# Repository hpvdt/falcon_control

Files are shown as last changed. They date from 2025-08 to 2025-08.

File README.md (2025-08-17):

>[!WARNING]
>The functionality of this board has been split between the new wing modules and flight sticks, so this hardware is redundant and will no longer be worked on.

# Control Board

This board is primarily meant to collect the inputs from the flight sticks over I2C and then operate control surface servos. In addition to this it also has the functionlity to read potentiometers on the control surfaces to verify the control surfaces are moving into the right position and even alerting the pilots if they fail to using a buzzer for attention and LEDs to specify the problematic surfaces.

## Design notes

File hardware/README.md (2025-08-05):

# Hardware

KiCad projects for the control boards.

## Revision 3

Most recent board. Current candidate for installation into Falcon.

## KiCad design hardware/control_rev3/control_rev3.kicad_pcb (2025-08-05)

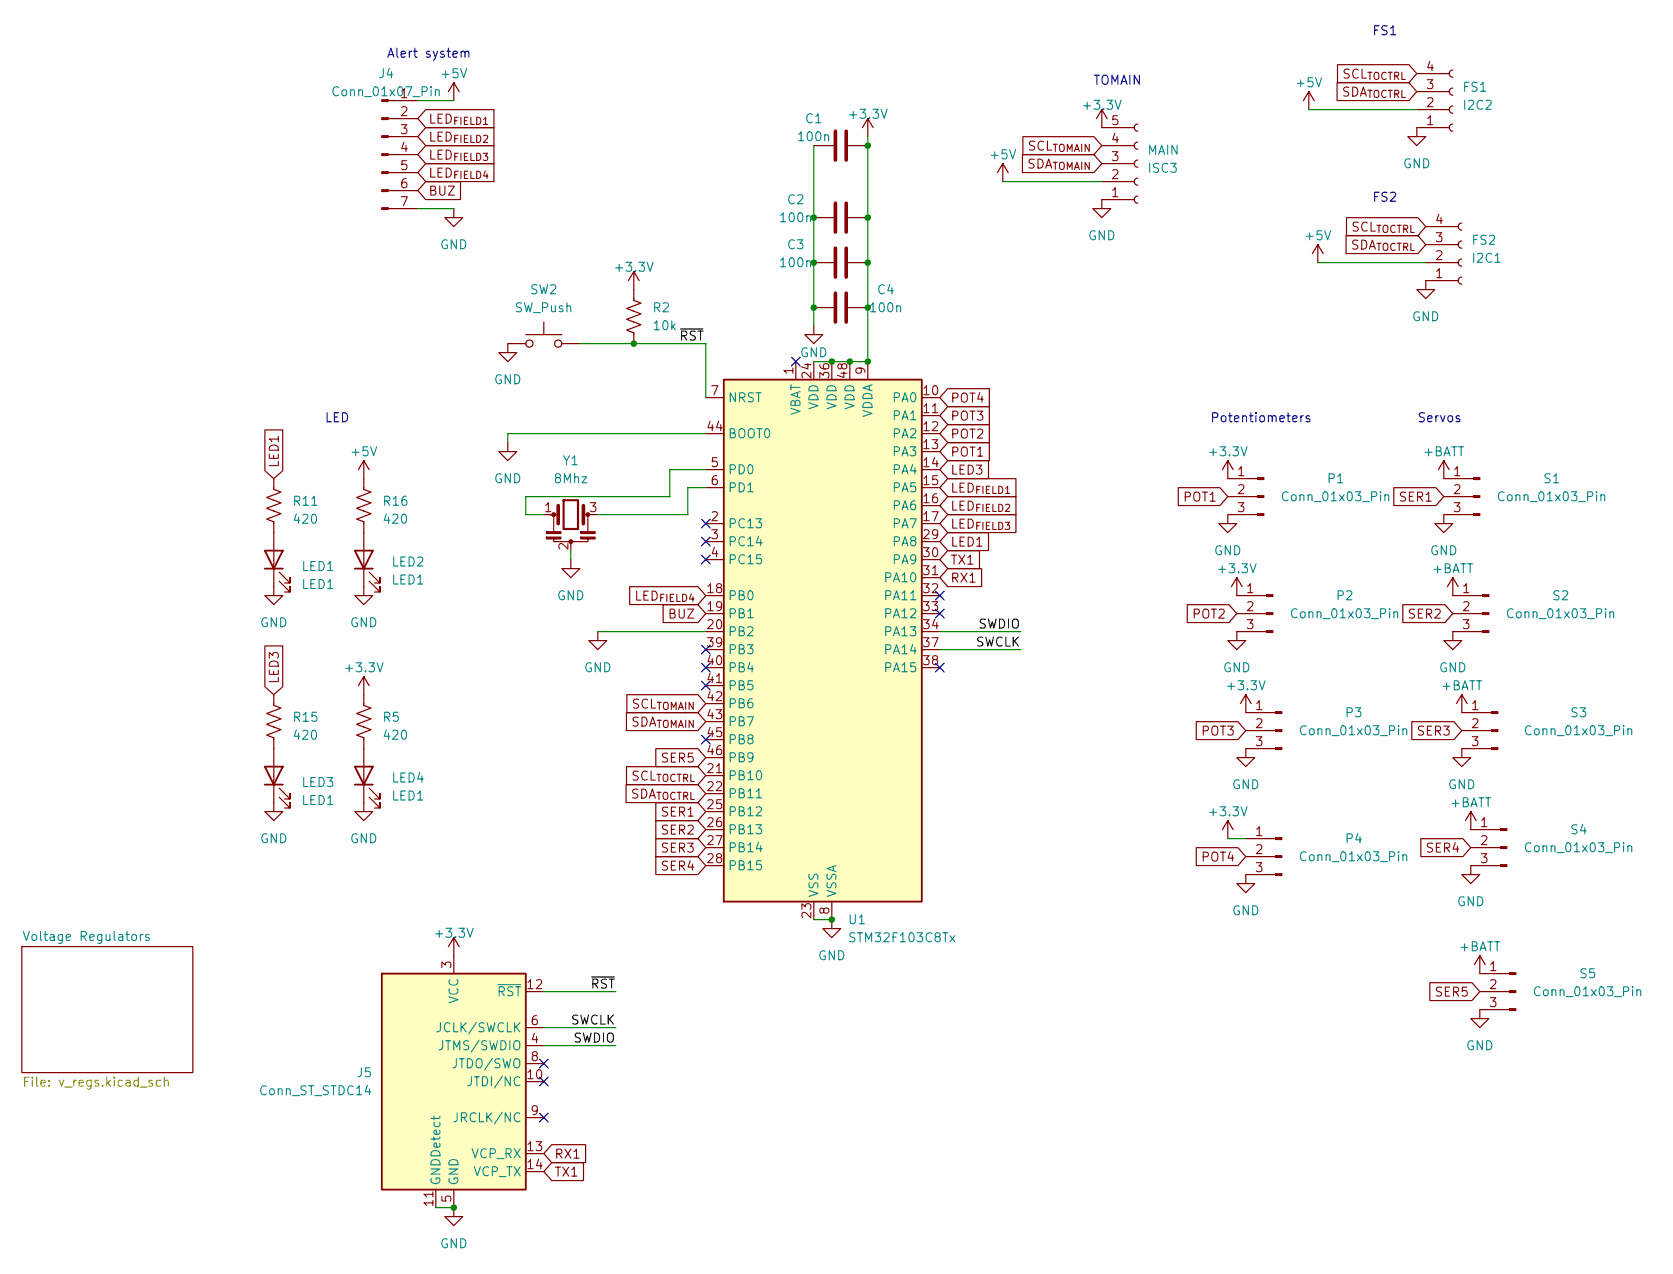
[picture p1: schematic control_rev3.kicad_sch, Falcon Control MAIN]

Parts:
C1, C2, C3, C4: 100n; C_0603_1608Metric
I2C1: FS2; JST_XH_B4B-XH-A_1x04_P2.50mm_Vertical
I2C2: FS1; JST_XH_B4B-XH-A_1x04_P2.50mm_Vertical
ISC3: MAIN; JST_XH_B5B-XH-A_1x05_P2.50mm_Vertical
J4: Conn_01x07_Pin; JST_XH_B7B-XH-A_1x07_P2.50mm_Vertical
J5: Conn_ST_STDC14; PinHeader_2x07_P1.27mm_Vertical_SMD
LED1, LED2, LED3, LED4: LED1; LED_0805_2012Metric_Pad1.15x1.40mm_HandSolder
P1, P2, P3, P4: Conn_01x03_Pin; JST_EH_B3B-EH-A_1x03_P2.50mm_Vertical
R2: 10k; R_0603_1608Metric
R5, R11, R15, R16: 420; R_0603_1608Metric
S1, S2, S3, S4, S5: Conn_01x03_Pin; JST_EH_B3B-EH-A_1x03_P2.50mm_Vertical
SW2: SW_Push; SW_SPST_B3U-1000P-B
U1: STM32F103C8Tx; LQFP-48_7x7mm_P0.5mm
Y1: 8Mhz; Resonator_SMD_Murata_CSTxExxV-3Pin_3.0x1.1mm

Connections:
+3.3V: C1.2, C2.2, C3.2, C4.1, ISC3.5, J5.3 (VCC), P1.1, P2.1, P3.1, P4.1, R2.1, R5.2, U1.9 (VDDA), U1.24 (VDD), U1.36 (VDD), U1.48 (VDD); also elsewhere on the board
+5V: I2C1.2, I2C2.2, ISC3.2, J4.1, R16.2; also elsewhere on the board
+BATT: S1.1, S2.1, S3.1, S4.1, S5.1; also elsewhere on the board
/SWCLK: J5.6 (JCLK/SWCLK), U1.37 (PA14)
/SWDIO: J5.4 (JTMS/SWDIO), U1.34 (PA13)
/~RST: J5.12 (~RST), R2.2, SW2.2, U1.7 (NRST)
BUZ: J4.6, U1.19 (PB1)
GND: C1.1, C2.1, C3.1, C4.2, I2C1.1, I2C2.1, ISC3.1, J4.7, J5.5 (GND), J5.7 (GND), J5.11 (GNDDetect), LED1.1 (K), LED2.1 (K), LED3.1 (K), LED4.1 (K), P1.3, P2.3, P3.3, P4.3, S1.3, S2.3, S3.3, S4.3, S5.3, SW2.1, U1.8 (VSSA), U1.20 (PB2), U1.23 (VSS), U1.35 (VSS), U1.44 (BOOT0), U1.47 (VSS), Y1.2; also elsewhere on the board
LED1: R11.2, U1.29 (PA8)
LED3: R15.2, U1.14 (PA4)
LED_{FIELD1}: J4.2, U1.15 (PA5)
LED_{FIELD2}: J4.3, U1.16 (PA6)
LED_{FIELD3}: J4.4, U1.17 (PA7)
LED_{FIELD4}: J4.5, U1.18 (PB0)
unnamed: LED1.2 (A), R11.1
unnamed: LED2.2 (A), R16.1
unnamed: LED3.2 (A), R15.1
unnamed: LED4.2 (A), R5.1
unnamed: U1.5 (PD0), Y1.1
unnamed: U1.6 (PD1), Y1.3
POT1: P1.2, U1.13 (PA3)
POT2: P2.2, U1.12 (PA2)
POT3: P3.2, U1.11 (PA1)
POT4: P4.2, U1.10 (PA0)
RX1: J5.13 (VCP_RX), U1.31 (PA10)
SCL_{TOCTRL}: I2C1.4, I2C2.4, U1.21 (PB10)
SCL_{TOMAIN}: ISC3.4, U1.42 (PB6)
SDA_{TOCTRL}: I2C1.3, I2C2.3, U1.22 (PB11)
SDA_{TOMAIN}: ISC3.3, U1.43 (PB7)
SER1: S1.2, U1.25 (PB12)
SER2: S2.2, U1.26 (PB13)
SER3: S3.2, U1.27 (PB14)
SER4: S4.2, U1.28 (PB15)
SER5: S5.2, U1.46 (PB9)
TX1: J5.14 (VCP_TX), U1.30 (PA9)

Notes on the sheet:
FS1
Servos
Alert system
FS2
TOMAIN
Potentiometers
LED

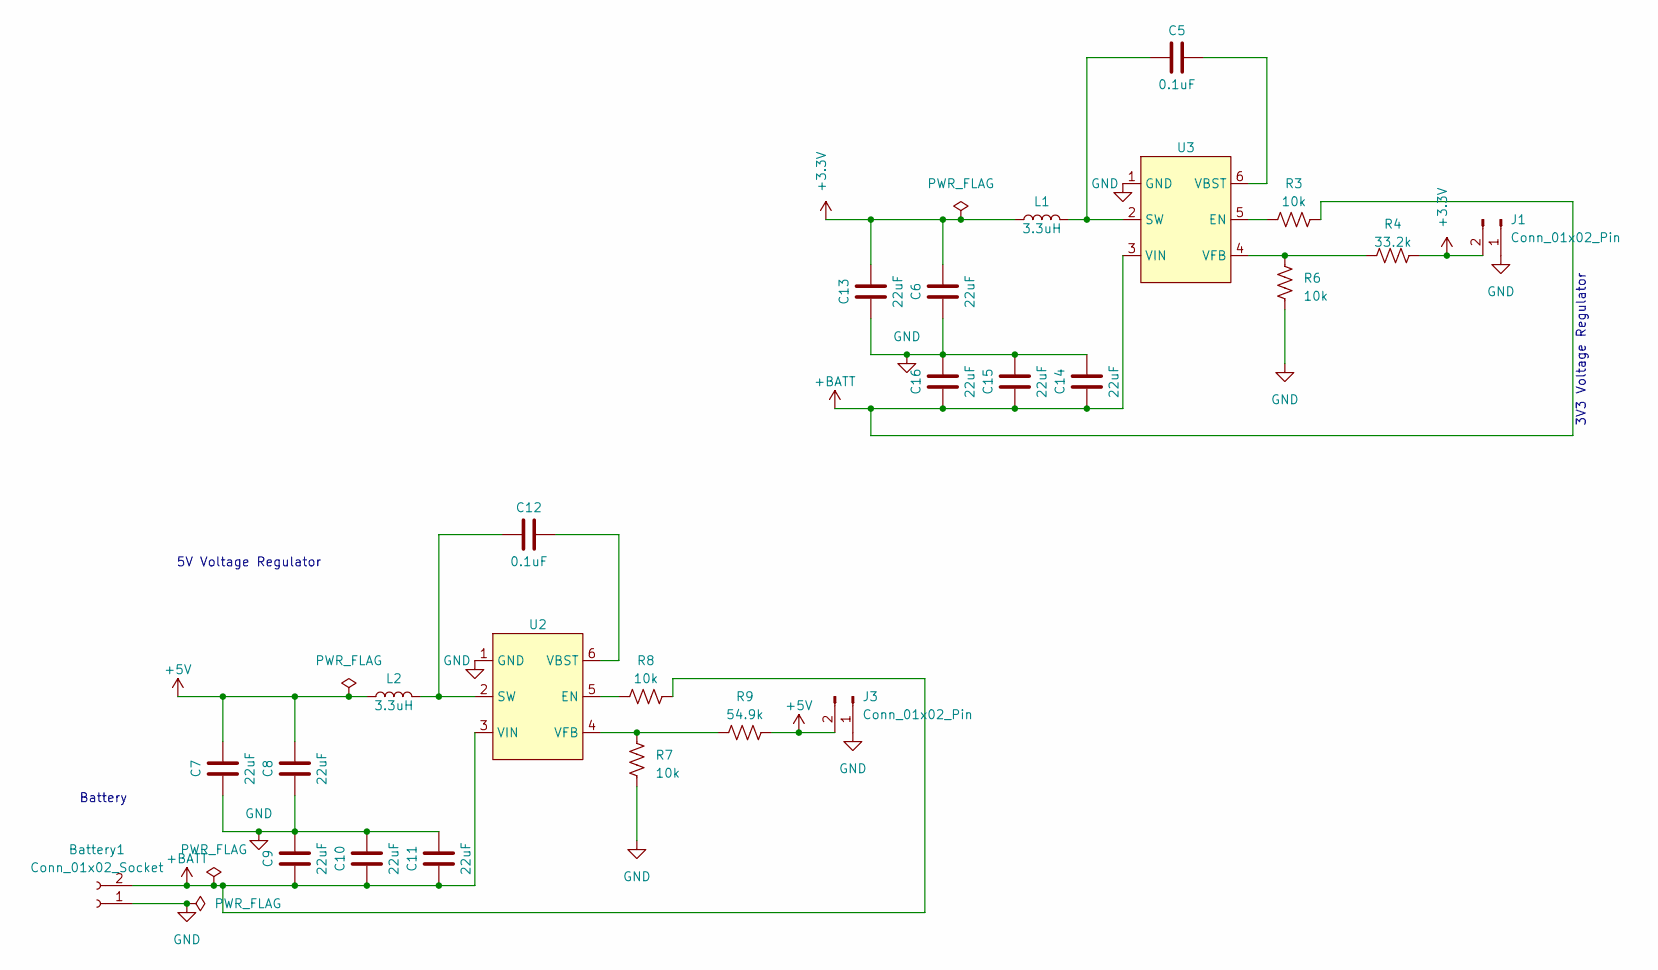
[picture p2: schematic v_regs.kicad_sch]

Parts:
Battery1: Conn_01x02_Socket; AMASS_XT60-M_1x02_P7.20mm_Vertical
C5, C12: 0.1uF; C_0805_2012Metric
C6, C7, C8, C9, C10, C11, C13, C14, C15, C16: 22uF; C_0805_2012Metric
J1, J3: Conn_01x02_Pin; JST_XH_B2B-XH-A_1x02_P2.50mm_Vertical
L1, L2: 3.3uH; L_Taiyo-Yuden_NR-60xx
R3, R6, R7, R8: 10k; R_0603_1608Metric
R4: 33.2k; R_0603_1608Metric
R9: 54.9k; R_0603_1608Metric
U2, U3: TSOT-23-6

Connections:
+3.3V: C6.2, C13.2, J1.2, L1.1, R4.1; also elsewhere on the board
+5V: C7.2, C8.2, J3.2, L2.1, R9.1; also elsewhere on the board
+BATT: Battery1.2, C9.1, C10.1, C11.1, C14.1, C15.1, C16.1, R3.2, R8.2, U2.3 (VIN), U3.3 (VIN); also elsewhere on the board
GND: Battery1.1, C6.1, C7.1, C8.1, C9.2, C10.2, C11.2, C13.1, C14.2, C15.2, C16.2, J1.1, J3.1, R6.1, R7.1, U2.1 (GND), U3.1 (GND); also elsewhere on the board
unnamed: R8.1, U2.5 (EN)
unnamed: C12.1, L2.2, U2.2 (SW)
unnamed: C12.2, U2.6 (VBST)
unnamed: R7.2, R9.2, U2.4 (VFB)
unnamed: R3.1, U3.5 (EN)
unnamed: C5.1, L1.2, U3.2 (SW)
unnamed: C5.2, U3.6 (VBST)
unnamed: R4.2, R6.2, U3.4 (VFB)

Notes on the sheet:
5V Voltage Regulator
3V3 Voltage Regulator
Battery

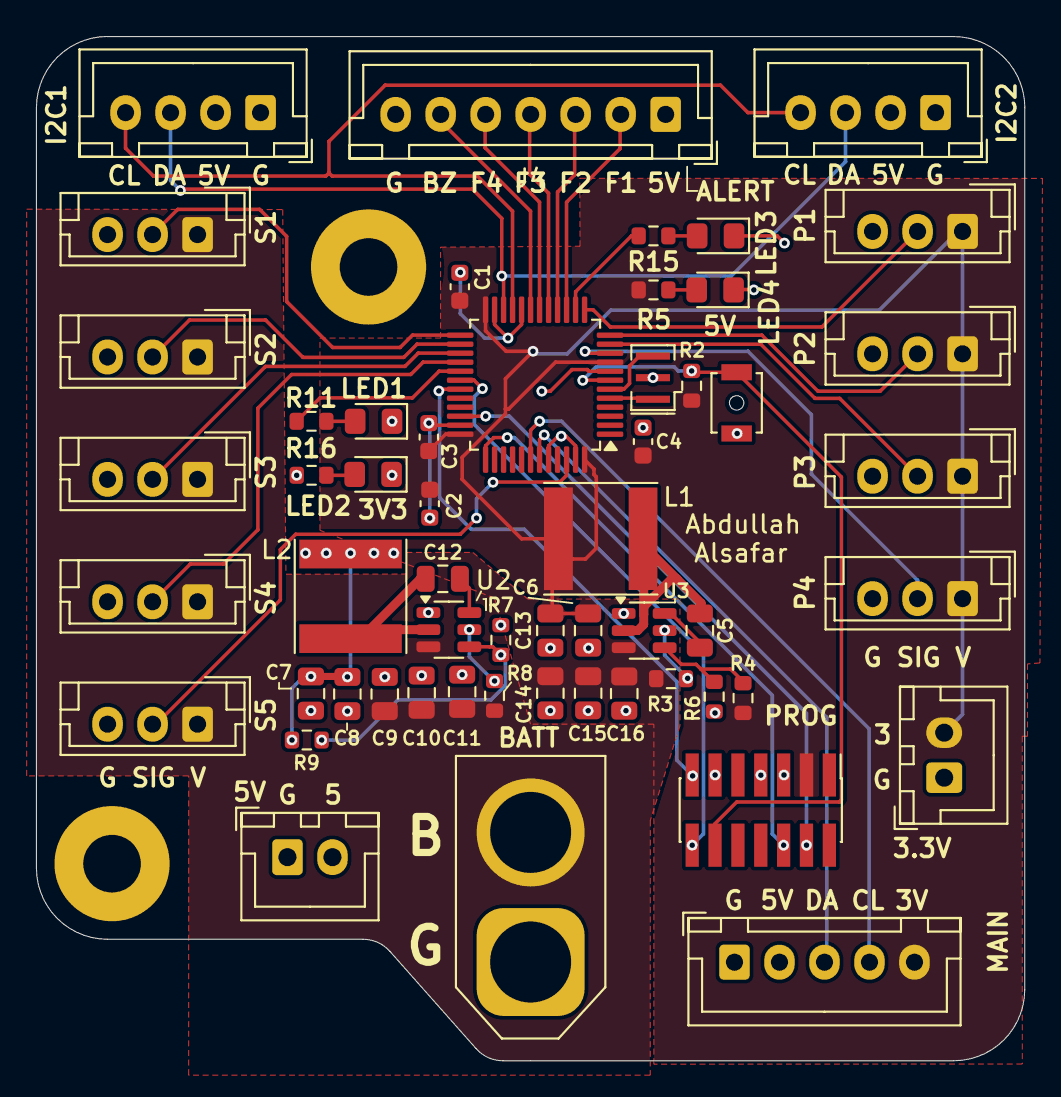
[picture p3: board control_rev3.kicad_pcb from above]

Board: 2 copper layers, 54.9 x 56.9 mm, 55 parts (0 on the bottom side), 43 nets.

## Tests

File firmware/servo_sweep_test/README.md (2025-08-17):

# falcon_control_servosweeptest
servo sweep test for controlboard

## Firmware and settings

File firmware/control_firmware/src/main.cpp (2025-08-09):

#include <Arduino.h>
#include <Servo.h>
#include <Wire.h>
#include "pin_allocations.hpp"
#include "control_surfaces.hpp"
#include "flight_stick_comms.hpp"
#include "flight_stick_state.h"

HardwareSerial debug_serial(PIN_DEBUG_RX, PIN_DEBUG_TX);

const int I2C_ADDRESS = 8;
TwoWire main_i2c(PIN_MAIN_SDA, PIN_MAIN_SCL);
TwoWire controller_i2c(PIN_CONTROLLER_SDA, PIN_CONTROLLER_SCL);
const uint8_t PILOT_ADDRESS = 0x23;

const int LED_ACTIVE = HIGH;
const int BUZZER_ACTIVE = HIGH;

// Contribution of RPY to each of the control surfaces
float contribution_matrix[CTRL_SRFC_COUNT][3] ={{  1.000,  0.000,  0.000}, 
                                                {  0.000,  1.000,  0.000}, 
                                                {  0.000,  0.000,  1.000}, 
                                                {  0.000,  1.000,  0.000}}; 

const unsigned long SURFACE_ALIGNMENT_ALERT_HOLD_MS = 2000;

void setup() {
    main_i2c.begin(I2C_ADDRESS);
    debug_serial.begin(115200);

    fs_setup_to_request(&main_i2c);

    ctrl_srfc_init(&debug_serial);

    pinMode(PIN_BUZZER, OUTPUT);
    pinMode(PIN_LED_STATUS_1, OUTPUT);
    pinMode(PIN_LED_STATUS_2, OUTPUT);
    
    digitalWrite(PIN_BUZZER, BUZZER_ACTIVE);
    digitalWrite(PIN_LED_STATUS_1, LED_ACTIVE);
    digitalWrite(PIN_LED_STATUS_2, LED_ACTIVE);
    delay(2000);
    digitalWrite(PIN_BUZZER, !BUZZER_ACTIVE);
    digitalWrite(PIN_LED_STATUS_1, !LED_ACTIVE);
    digitalWrite(PIN_LED_STATUS_2, !LED_ACTIVE);
}

void loop() {
    const unsigned long CURRENT_MS = millis();

    struct FlightStickState user_input;
    fs_read_complete(PILOT_ADDRESS, &user_input);

    float surface_angle[CTRL_SRFC_COUNT] = {0};
    for (int s = 0; s < CTRL_SRFC_COUNT; s++) {
        surface_angle[s] =  contribution_matrix[s][0] * (float)user_input.axis_pitch;
        surface_angle[s] += contribution_matrix[s][1] * (float)user_input.axis_roll;
        surface_angle[s] += contribution_matrix[s][2] * (float)user_input.axis_yaw;
    }

    for (int i = 0; i < CTRL_SRFC_COUNT; i++) ctrl_srfc_set((enum ControlSurface) i, surface_angle[i]);

    // Add some buzzing if any surface is still out of line after a timeout
    // Timeout is needed to ignore transitions
    bool mis_match[CTRL_SRFC_COUNT];
    ctrl_srfc_check_state_all(mis_match);

    static unsigned long unaligned_since_ms[CTRL_SRFC_COUNT];
    bool buzzer_on = false;
    for (int i = 0; i < CTRL_SRFC_COUNT; i++) {
        if (mis_match[i] == false) {
            unaligned_since_ms[i] = 0;
            continue;
        }

        if (unaligned_since_ms == 0) unaligned_since_ms[i] = CURRENT_MS;
        if (CURRENT_MS - unaligned_since_ms[i] > SURFACE_ALIGNMENT_ALERT_HOLD_MS) buzzer_on = true;
    }
    if (buzzer_on) digitalWrite(PIN_BUZZER, BUZZER_ACTIVE);
    else digitalWrite(PIN_BUZZER, !BUZZER_ACTIVE);
    
    delay(20);
}

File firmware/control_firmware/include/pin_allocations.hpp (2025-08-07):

#ifndef CONTROL_PIN_ALLOCATIONS_H
#define CONTROL_PIN_ALLOCATIONS_H

#include <Arduino.h>

#define PIN_DEBUG_RX PA10
#define PIN_DEBUG_TX PA9

#define PIN_MAIN_SDA PB7
#define PIN_MAIN_SCL PB6

#define PIN_CONTROLLER_SDA PB11
#define PIN_CONTROLLER_SCL PB10

#define PIN_BUZZER PB1

#define PIN_LED_STATUS_1 PA8
#define PIN_LED_STATUS_2 PA4

#define NUM_SERVOS 5
#define PIN_SERVO_1 PB12
#define PIN_SERVO_2 PB13
#define PIN_SERVO_3 PB14
#define PIN_SERVO_4 PB15
#define PIN_SERVO_5 PB9

#define NUM_POTENTIOMETERS 4
#define PIN_POTENTIOMETER_1 PA3
#define PIN_POTENTIOMETER_2 PA2
#define PIN_POTENTIOMETER_3 PA1
#define PIN_POTENTIOMETER_4 PA0

#define NUM_LED_FIELDS 4
#define PIN_LED_FIELD_1 PA5
#define PIN_LED_FIELD_2 PA6
#define PIN_LED_FIELD_3 PA7
#define PIN_LED_FIELD_4 PB0
#define PIN_LED_FIELD_ACTIVE HIGH

extern const int PIN_SERVOS[NUM_SERVOS];
extern const int PIN_POTENTIOMETERS[NUM_POTENTIOMETERS];
extern const int PIN_LED_FIELD[NUM_LED_FIELDS];

#endif

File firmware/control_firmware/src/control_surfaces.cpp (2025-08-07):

#include <Arduino.h>
#include <Servo.h>
#include "pin_allocations.hpp"

#include "control_surfaces.hpp"


Servo actuator[NUM_SERVOS];
const int ACTUATOR_DEFAULT = 90;
const int ACTUATOR_MINIMUM = 90;
const int ACTUATOR_MAXIMUM = 90;

float target_angles_deg[4];

float calculate_servo_angle(enum ControlSurface surface, float target) {
    float angle_out;

    // Some math to convert the desired surface angle to a servo based on the linkage system
    switch (surface) {
    case CTRL_SRFC_RGHT_TIP:
        angle_out = target;
        break;
    case CTRL_SRFC_LFT_TIP:
        angle_out = target;
        break;
    case CTRL_SRFC_RDR:
        angle_out = target;
        break;
    case CTRL_SRFC_ELVTR:
        angle_out = target;
        break;
    
    default:
        angle_out = 0;
        break;
    }

    return angle_out;
}

void ctrl_srfc_init(Stream* debug) {
    for (int i = 0; i < NUM_SERVOS; i++) {
        pinMode(PIN_SERVOS[i], OUTPUT);
        actuator[i].attach(PIN_SERVOS[i]);
        actuator[i].write(ACTUATOR_DEFAULT);
    }

    for (int i = 0; i < NUM_LED_FIELDS; i++) {
        pinMode(PIN_LED_FIELD[i], OUTPUT);
    }

    for (int i = 0; i < NUM_POTENTIOMETERS; i++) {
        pinMode(PIN_POTENTIOMETERS[i], INPUT_ANALOG);
    }

    if (debug != nullptr) debug->println(F("Control surfaces setup"));

    if (debug != nullptr) debug->println(F("Control surfaces sweeping"));
    for (int i = 0; i < CTRL_SRFC_COUNT; i++) actuator[i].write(ACTUATOR_MINIMUM);
    delay(1000);
    for (int i = 0; i < CTRL_SRFC_COUNT; i++) actuator[i].write(ACTUATOR_MAXIMUM);
    delay(1000);
    for (int i = 0; i < CTRL_SRFC_COUNT; i++) actuator[i].write(ACTUATOR_DEFAULT);
    delay(1000);
    if (debug != nullptr) debug->println(F("Control surfaces completed sweep"));
}

void ctrl_srfc_set(enum ControlSurface surface, float angle_deg) {
    float angle_out_deg = calculate_servo_angle(surface, angle_deg);

    // Could add some error checking here

    target_angles_deg[surface] = angle_out_deg;
    actuator[surface].write(angle_out_deg);
}

float ctrl_srfc_read_surface(enum ControlSurface query) {
    uint32_t raw = analogRead(PIN_POTENTIOMETERS[query]);
    
    float angle_read_deg = (raw - 512) / (512.0 / 180.0);

    return angle_read_deg;
}

void ctrl_srfc_check_state_all(bool feedback[]) {
    const float ANGLE_TOLERANCE_DEG = 3;

    for (int i = 0; i < CTRL_SRFC_COUNT; i++) {
        float target_deg = target_angles_deg[i];
        float current_deg = ctrl_srfc_read_surface((enum ControlSurface) i);

        float delta_deg = fabs(target_deg - current_deg);
        bool in_tolerance = delta_deg <= ANGLE_TOLERANCE_DEG;

        if (feedback != nullptr) feedback[i] = in_tolerance;

        if (in_tolerance) digitalWrite(PIN_LED_FIELD[i], !PIN_LED_FIELD_ACTIVE);
        else digitalWrite(PIN_LED_FIELD[i], PIN_LED_FIELD_ACTIVE);
    }
}

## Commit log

2024-03-16 added potentiometers & added conditionals for LEDs
2025-08-05 Arranged files in new scheme
    [control_rev3.kicad_pcb, control_rev3.kicad_sch, v_regs.kicad_sch]
2025-08-05 Updated to KiCad 9
    [control_rev3.kicad_pcb, control_rev3.kicad_sch, v_regs.kicad_sch]
2025-08-05 Centralized pin allocations
2025-08-09 Changed boot to flash/buzz
    [main.cpp]
2025-08-09 Drafted I2C comms to flight sticks
2025-08-17 Added servo sweep test
